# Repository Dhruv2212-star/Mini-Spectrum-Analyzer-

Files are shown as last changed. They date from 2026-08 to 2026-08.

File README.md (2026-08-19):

**Ai ussage**- used to find correct parts for the build and help choose the correct MCU for this project & debugging the firmware and  STM32 **ONLY**.  

**Project Description**- The Mini Spectrum Analyzer is a compact electronic device designed to detect and display radio frequency (RF) signals over a selected frequency range. 

It uses an ADF4351 frequency synthesizer to generate a programmable local oscillator and an ADL5801 mixer to convert the received RF signal into an intermediate frequency.  

The AD8313 logarithmic detector measures the signal strength, while the STM32G031K8T6 microcontroller processes the data and displays the spectrum on an SPI TFT display.  

Power input- The device is powered through a USB-C connector and includes onboard power regulation, protection circuitry, user control buttons, status indicators for easy debugging.  

*Designed in Kicad 10.0.3 as 4 layered PCB with independent power planes such as GND & +3v3*

**Note to reviewer**- the Format of the Readme is kept in tabular manner to keep things organized and easy to read. instead of long para i have used tables which i created in excel and pasted it into git file;. if you do have any further question regarding to my project, feel free to reach out to me on slack where i can explain it to you if you want.  
**[slack id- U0AFT499S6S,  Magic tree/Dhruv Patel]**
------------------------------------------------------------------------------------------------------------------------------------------
# Firmware Flashing Guide  
Don't flash the ZIP directly, The ZIP contains the ADF4351 driver source, not a ready-to-flash .bin  
You first need an STM32 project that compiles it, Create the STM32 project In STM32CubeIDE, create a project for: STM32G031K8T6  
Then configure the pins to match our PCB 
The ADF4351 uses a 3-wire serial interface and accepts a programmable 35 MHz–4.4 GHz output range.  
Now *Configure SPI1  
In CubeMX the following:  
SPI1 → Master  
8-bit  
MSB first  
CPOL = Low  
CPHA = 1st Edge  
Software NSS  
Configure PA4, PA5 and PA7 for the SPI interface, with PA4 ultimately serving as the ADF4351 LE control  
Add the driver. From the ZIP, copy: adf4351.h, adf4351.c  

into your CubeIDE project:  
Core/Inc/adf4351.h  
Core/Src/adf4351.c  
Then copy the initialization from: Maine.c to main.c  
now, Set your actual reference  
Our PCB uses:  
Y1 = 10 MHz TCXO  
hz = 10000000UL  
The ADF4351's reference/PFD configuration is important because it directly affects the generated frequency.  
->Build the project  
In CubeIDE:  
Project → Build Project  

 If it has:  
0 errors  
0 warnings related to the driver, ONLY then proceed 

*Connect your ST-LIN  
Use your J4 SWD header:  
J4-1 > SWDIO  
J4-2 > SWCLK   
J4-3 > NRST  
J4-4 > +3V3 / VTREF  
J4-5 > GND  
First test: don't test the spectrum analyzer yet  

Connect the ST-LINK to your PC and open STM32CubeProgrammer. ST officially supports programming STM32 devices through ST-LINK/SWD, and CubeProgrammer can program and verify the MCU flash  
Click:  
ST-LINK > SWD > Connect  
If it detects your STM32G031, stop there and tell me that it connected successfully.  
**Then we'll flash it**  
Compile > generate .elf > flash > reset > verify ADF4351 lock > check RF output  

so the driver is configured for:  

| STM32 U5 | ADF4351 U3 |
| --- | --- |
| PA4 — pin 11 | LE — pin 3 |
| PA5 — pin 12 | CLK — pin 1  |
| PA7 — pin 14 | DATA — pin 2 |
| PB0 — pin 15 | CE — pin 4 |
| PA1 — pin 8  | LD — pin 25  |

------------------------------------------------------------------------------------------------------------------------------------------
# PCB component's Role in the circuit 
 # Block 1 — USB-C Power Input & Protection
   

 | Ref | Component        | Role in the Circuit    |                                                                                     
| --- | ---------------- | ----------------------------------------------------------------------------------------------------------------------------------------- |
| J1  | USB-C Receptacle | Receives 5 V power from a USB-C source and serves as the main power input to the spectrum analyzer.                                          |
| F1  | Polyfuse         | Protects the board from excessive current by disconnecting the supply during a fault and automatically resetting after the fault is removed. |
| D1  | TVS/ESD Diode    | Protects the USB power line against electrostatic discharge and voltage spikes that could damage sensitive components.                       |
| R1  | 5.1 kΩ           | USB-C CC1 pull-down resistor that identifies the board as a power sink.                                                                      |
| R2  | 5.1 kΩ           | USB-C CC2 pull-down resistor that enables correct cable orientation detection.                                                               |
| C1  | 10 µF            | Reduces low-frequency voltage ripple and provides energy storage during sudden load changes.                                                 |
| C2  | 100 nF           | Filters high-frequency noise on the incoming USB power line.                                                                                 |

# Block 2 — 5 V to 3.3 V Power Regulation
  

| Ref | Component | Role in the Circuit |
| --- | --- | --- |
| U1  | 3.3 V Regulator | Converts the incoming 5 V supply into a stable 3.3 V rail for the digital and RF circuitry. |
| L1  | Ferrite Bead | Suppresses high-frequency switching noise between the regulator and the clean 3.3 V rail. |
| C3  | 10 µF | Stabilizes the regulator input and output while improving transient response. |
| C4  | 100 nF | High-frequency bypass capacitor for the regulator output. |
| C5  | 100 nF | Additional local decoupling capacitor to maintain a clean supply. |

# Block 3 — RF Input & Signal Conditioning
  

| Ref | Component | Role in the Circuit |
| --- | --- | --- |
| R6  | 10 Ω | Provides input damping and limits RF transients entering the signal path. |
| R7  | 10 Ω | Works with R6 to improve signal integrity and reduce ringing. |
| C6  | 100 pF | AC-couples the RF signal while blocking DC from reaching the mixer stage. |
| D2  | PESD5V0X1UL | Protects the RF input against electrostatic discharge events. |

# Block 4 — RF Detector & Block 5 — Frequency Generation, Mixer & IF Stage  


| Ref | Component | Role in the Circuit |
| --- | --- | --- |
| U2 | AD8313 | Converts the RF signal level into a proportional DC voltage that the MCU can measure. |
| C7–C10 | Decoupling Capacitors | Filter supply noise and maintain stable operation of the RF detector. |

| REf | Component | Role in the Circuit |
| --- | --- | --- |
| U3 | ADF4351 | Generates a programmable local oscillator signal used to sweep the analyzer across different frequencies. |
| U4 | ADL5801 | Mixes the incoming RF signal with the local oscillator to produce an intermediate-frequency signal. |
| Y1 | 10 MHz TCXO | Provides a highly stable reference clock for accurate frequency generation. |
| T1 | ADT4-1T+ Transformer | Converts the differential IF signal into the required form while providing impedance matching. |
| R11–R15 | Bias / PLL Resistors | Set PLL operating conditions, bias RF outputs, and configure the frequency synthesizer. |
| C11–C22 | Coupling / Decoupling Capacitors | Provide AC coupling, supply filtering, RF bypassing, and PLL loop-filter functions required for stable RF operation. |

# Block 6 — MCU, Display & Programming & Block 7 — User Interface  


| Ref | Component | Role in the Circuit |
| --- | --- | --- |
| U5  | STM32G031K8T6 | Controls the analyzer, programs the synthesizer, samples detector data, processes measurements, and updates the display. |
| J3  | ST7789 Display Module | Displays the measured spectrum, menus, and analyzer information to the user. |
| J4  | SWD Header | Allows firmware programming and debugging of the microcontroller. |
| R16 | 10 kΩ | Pull-up resistor for the MCU reset pin, ensuring reliable startup. |
| C24 | 100 nF | High-frequency bypass capacitor for the MCU supply. |
| C25 | 4.7 µF | Bulk decoupling capacitor that stabilizes the MCU power rail during rapid current changes. |

| Ref | Component | Role in the Circuit |
| --- | --- | --- |
| SW1 | Push Button | Increases frequency or navigates upward through menus. |
| SW2 | Push Button | Decreases frequency or navigates downward through menus. |
| SW3 | Push Button | Selects menu options and confirms user actions. |
| R17 | 10 kΩ | Pull-up resistor for SW1 input. |
| R18 | 10 kΩ | Pull-up resistor for SW2 input. |
| R19 | 10 kΩ | Pull-up resistor for SW3 input. |
screenshot of PCB

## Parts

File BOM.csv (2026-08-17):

Reference | Value | Quantity | Symbol | Footprint
J1 | USB-C Receptacle | 1 | Connector_USB:USB_C_Receptacle_HRO_TYPE-C-31-M-12 | Connector_USB:USB_C_Receptacle_HRO_TYPE-C-31-M-12
F1 | Polyfuse | 1 | Device:Polyfuse | Fuse:Fuse_1206_3216Metric
D1 | ESD/TVS | 1 | Device:D_TVS | Diode_SMD:D_SOD-323
C1 | 10uF | 1 | Device:C | Capacitor_SMD:C_0603_1608Metric
C2 | 100nF | 1 | Device:C | Capacitor_SMD:C_0603_1608Metric
U1 | 3.3V Regulator | 1 | Regulator_Linear | Package_TO_SOT_SMD:SOT-23-5
L1 | Ferrite Bead | 1 | Device:L | Inductor_SMD:L_0603_1608Metric
C3 | 10uF | 1 | Device:C | Capacitor_SMD:C_0603_1608Metric
C4 | 100nF | 1 | Device:C | Capacitor_SMD:C_0603_1608Metric
C5 | 100nF | 1 | Device:C | Capacitor_SMD:C_0603_1608Metric
R6 | 10Ω | 1 | Device:R | Resistor_SMD:R_0603_1608Metric
R7 | 10Ω | 1 | Device:R | Resistor_SMD:R_0603_1608Metric
C6 | 100pF | 1 | Device:C | Capacitor_SMD:C_0603_1608Metric
D2 | PESD5V0X1UL | 1 | Device:D | Diode_SMD:D_SOD-882
U2 | AD8313 | 1 | RF:AD8313 | Package_TO_SOT_SMD:SOT-363_SC-70-6
U3 | ADF4351 | 1 | Timer_PLL:ADF4351 | Package_DFN_QFN:LFCSP-32_5x5mm_P0.5mm
U4 | ADL5801 | 1 | RF_Mixer:ADL5801 | Package_DFN_QFN:LFCSP-24_4x4mm_P0.5mm
Y1 | 10MHz TCXO | 1 | Oscillator:TCXO | Oscillator:Oscillator_SMD_2.0x1.6mm
T1 | ADT4-1T+ | 1 | Transformer:ADT4-1T | RF_Mini-Circuits:Mini-Circuits_CD542_H2.84mm
R11 | 50Ω | 1 | Device:R | Resistor_SMD:R_0603_1608Metric
R12 | 50Ω | 1 | Device:R | Resistor_SMD:R_0603_1608Metric
R13 | 5.1kΩ | 1 | Device:R | Resistor_SMD:R_0603_1608Metric
R14 | PLL Filter | 1 | Device:R | Resistor_SMD:R_0603_1608Metric
R15 | 50Ω | 1 | Device:R | Resistor_SMD:R_0603_1608Metric
C11 | 1nF | 1 | Device:C | Capacitor_SMD:C_0603_1608Metric
C12 | 1nF | 1 | Device:C | Capacitor_SMD:C_0603_1608Metric
C13 | 1nF | 1 | Device:C | Capacitor_SMD:C_0603_1608Metric
C14 | 100pF | 1 | Device:C | Capacitor_SMD:C_0603_1608Metric
C15 | 100pF | 1 | Device:C | Capacitor_SMD:C_0603_1608Metric
C16 | 100nF | 1 | Device:C | Capacitor_SMD:C_0603_1608Metric
C17 | 100nF | 1 | Device:C | Capacitor_SMD:C_0603_1608Metric
C18 | 100nF | 1 | Device:C | Capacitor_SMD:C_0603_1608Metric
C19 | 100nF | 1 | Device:C | Capacitor_SMD:C_0603_1608Metric
C20 | 100nF | 1 | Device:C | Capacitor_SMD:C_0603_1608Metric
C21 | 100nF | 1 | Device:C | Capacitor_SMD:C_0603_1608Metric
C22 | 100nF | 1 | Device:C | Capacitor_SMD:C_0603_1608Metric
U5 | STM32G031K8T6 | 1 | MCU_ST_STM32G0:STM32G031K8Tx | Package_QFP:LQFP-32_7x7mm_P0.8mm
U6 | ST7789 Module | 1 | Connector_Generic:Conn_01x12 | Connector_PinHeader_2.54mm:PinHeader_1x12_P2.54mm_Vertical
J4 | SWD Header | 1 | Connector_Generic:Conn_01x05 | Connector_PinHeader_2.54mm:PinHeader_1x05_P2.54mm_Vertical
R16 | 10kΩ | 1 | Device:R | Resistor_SMD:R_0603_1608Metric
C24 | 100nF | 1 | Device:C | Capacitor_SMD:C_0603_1608Metric
C25 | 4.7uF | 1 | Device:C | Capacitor_SMD:C_0603_1608Metric
SW1 | Tactile Switch | 1 | Switch:SW_Push | Button_Switch_SMD:SW_SPST_SKQG_WithoutStem
SW2 | Tactile Switch | 1 | Switch:SW_Push | Button_Switch_SMD:SW_SPST_SKQG_WithoutStem
SW3 | Tactile Switch | 1 | Switch:SW_Push | Button_Switch_SMD:SW_SPST_SKQG_WithoutStem
R17 | 10kΩ | 1 | Device:R | Resistor_SMD:R_0603_1608Metric
R18 | 10kΩ | 1 | Device:R | Resistor_SMD:R_0603_1608Metric
R19 | 10kΩ | 1 | Device:R | Resistor_SMD:R_0603_1608Metric
D3 | Green LED | 1 | Device:LED | LED_SMD:LED_0603_1608Metric
R20 | 1kΩ | 1 | Device:R | Resistor_SMD:R_0603_1608Metric
TP1 | +5V | 1 | Connector:TestPoint | TestPoint:TestPoint_Pad_D1.5mm
TP2 | +3V3 | 1 | Connector:TestPoint | TestPoint:TestPoint_Pad_D1.5mm
TP3 | GND | 1 | Connector:TestPoint | TestPoint:TestPoint_Pad_D1.5mm
TP4 | RF | 1 | Connector:TestPoint | TestPoint:TestPoint_Pad_D1.5mm

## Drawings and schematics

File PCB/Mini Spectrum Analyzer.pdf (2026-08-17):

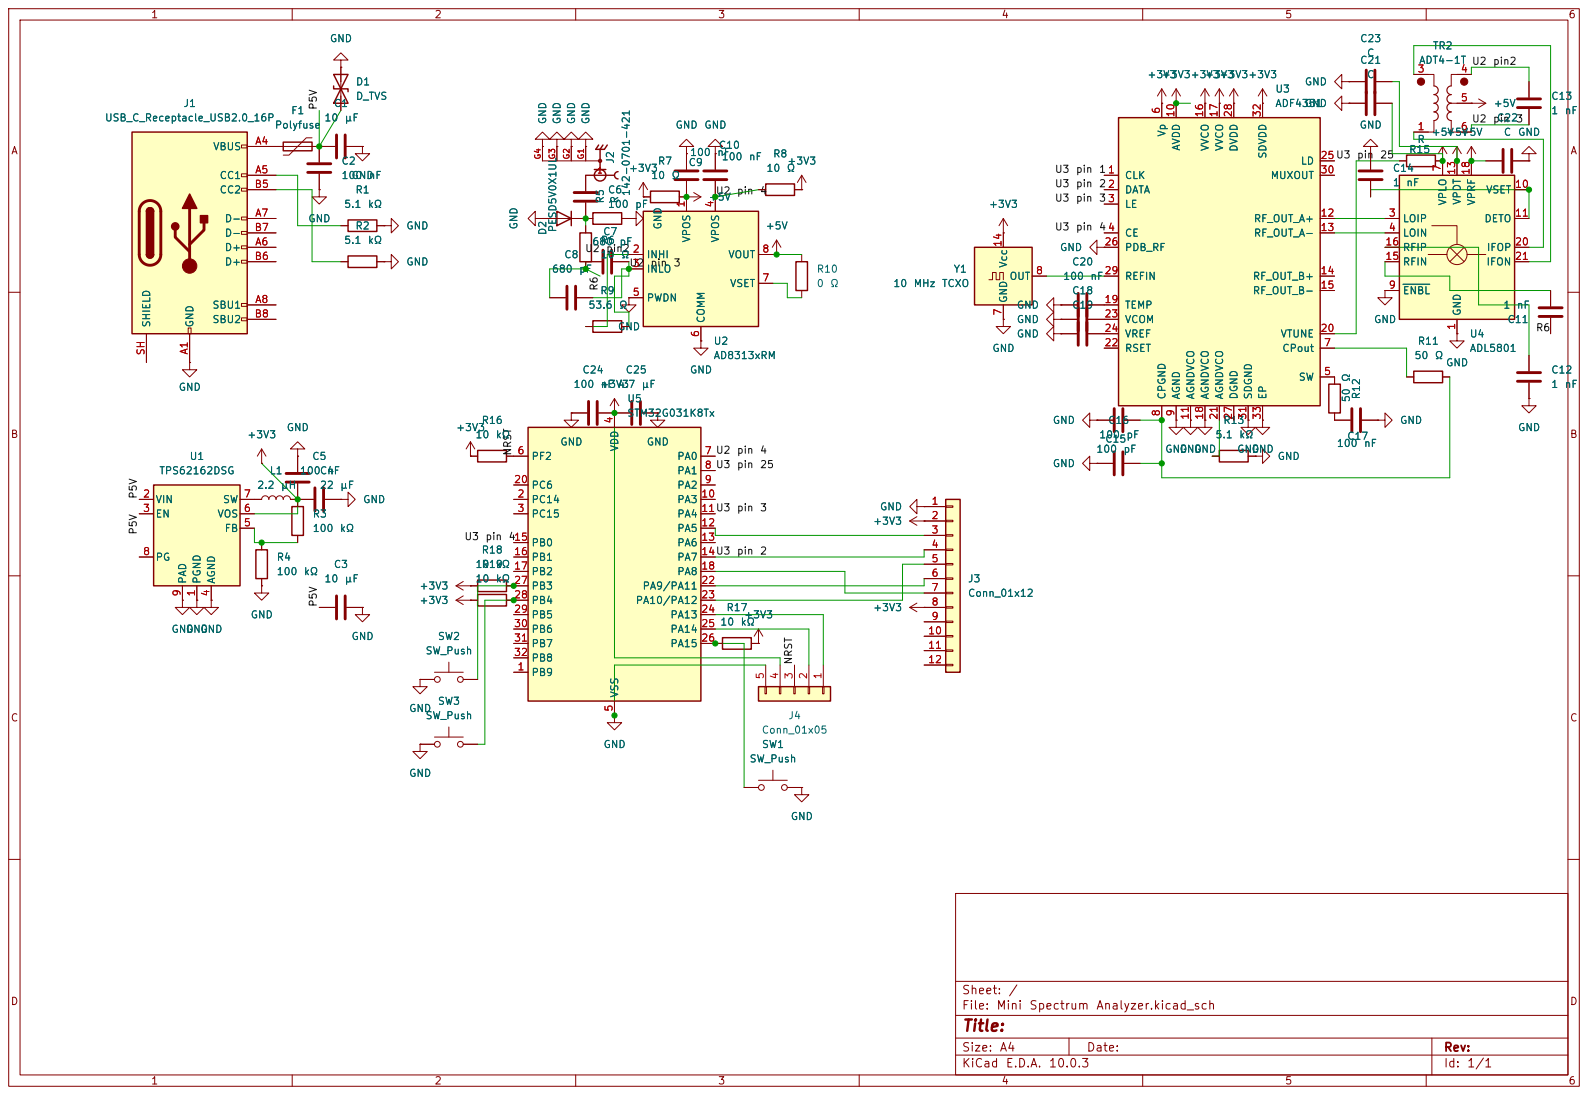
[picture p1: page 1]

9 AVDD 10 AGNDVCO 11 RF_OUT_A+ 12 RF_OUT_A- 13 RF_OUT_B+ 14 RF_OUT_B- 15 VVCO 16 VVCO 17 AGNDVCO 18

Sheet: /
File: Mini Spectrum Analyzer.kicad_sch
Title:

Size: A4 | Rev:
KiCad E.D.A. 10.0.3 | Id: 1/1

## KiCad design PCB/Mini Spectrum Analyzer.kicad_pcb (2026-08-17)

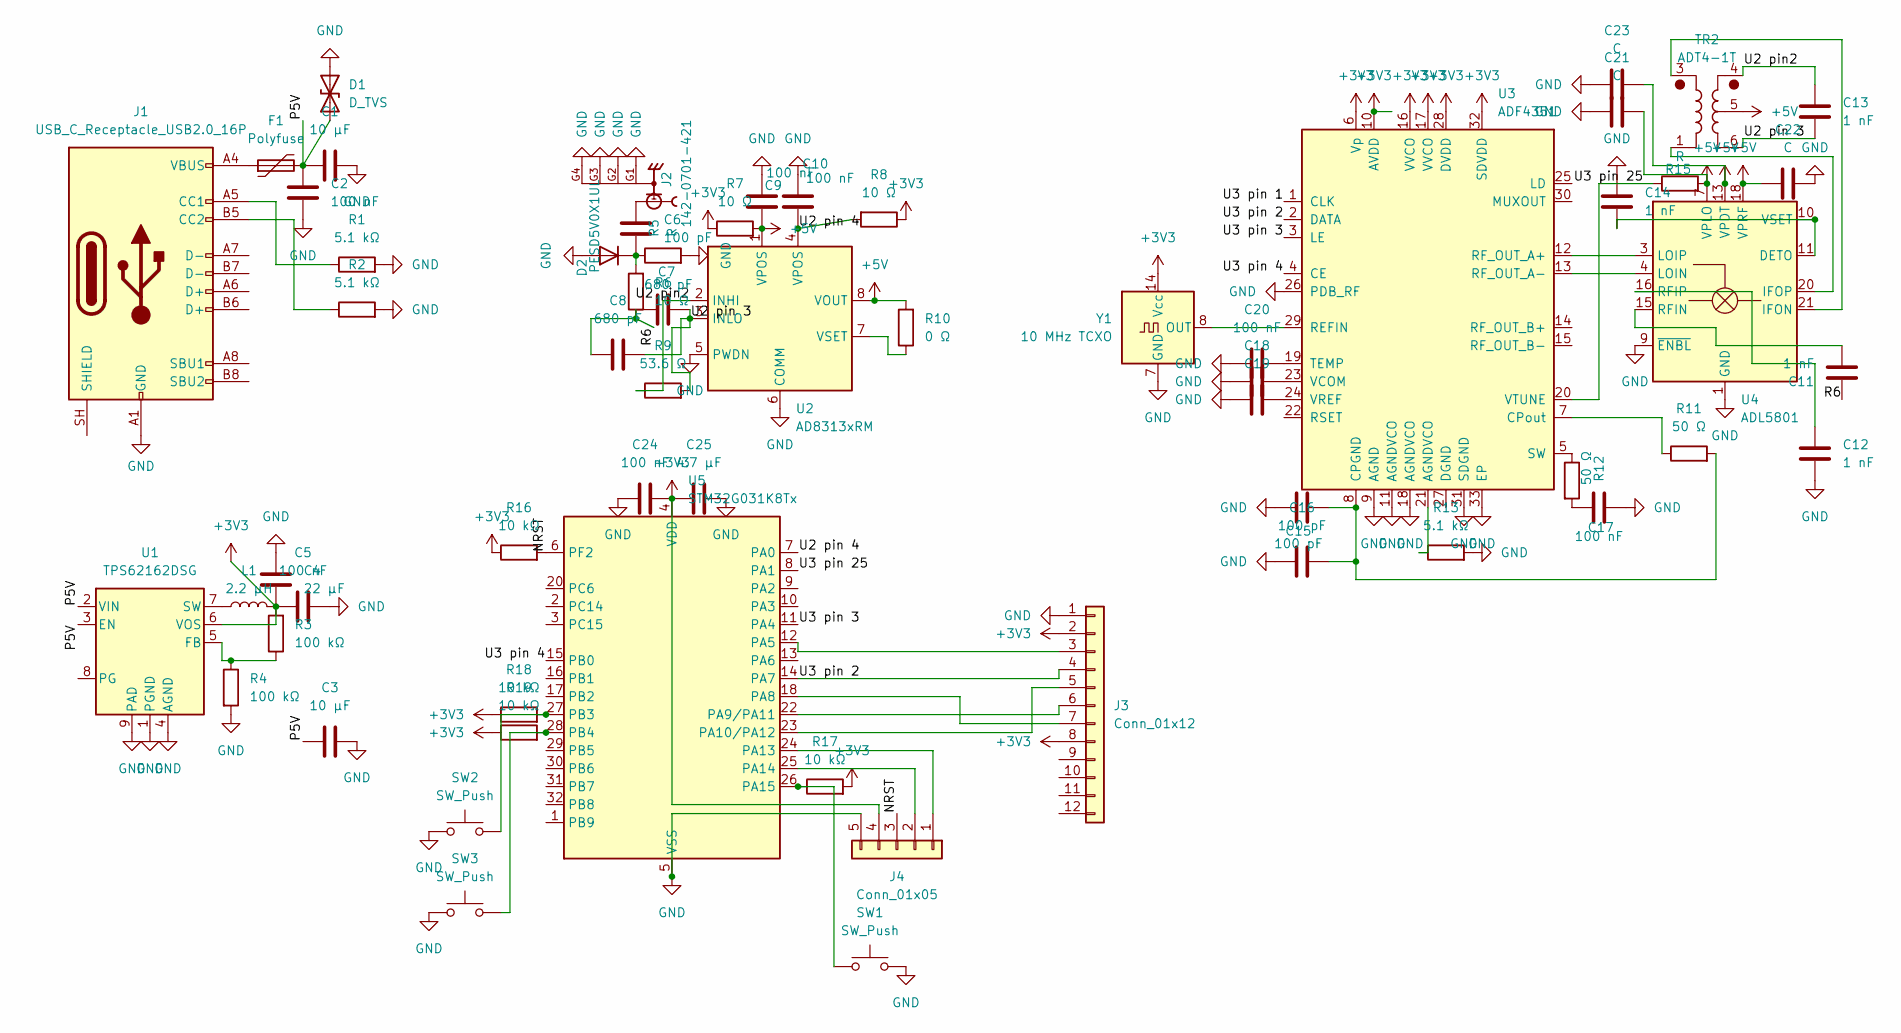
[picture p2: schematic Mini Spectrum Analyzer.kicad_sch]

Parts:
C1: 10 µF; C_1206_3216Metric
C2, C5, C9, C10, C17, C20, C24: 100 nF; C_0603_1608Metric
C3: 10 µF; C_0805_2012Metric
C4: 22 µF; C_0805_2012Metric
C6, C15, C16: 100 pF; C_0603_1608Metric
C7, C8: 680 pF; C_0603_1608Metric
C11, C12, C13, C14: 1 nF; C_0603_1608Metric
C18, C19: C_0603_1608Metric
C21, C22, C23: C; C_0603_1608Metric
C25: 4.7 µF; C_0603_1608Metric
D1: D_TVS; D_SMB
D2: PESD5V0X1UL; D_SOD-523
F1: Polyfuse; Fuse_1206_3216Metric
J1: USB_C_Receptacle_USB2.0_16P; USB_C_Receptacle_GCT_USB4105-xx-A_16P_TopMnt_Horizontal
J2: 142-0701-421; CINCH_142-0701-421; PARTREV 1a
J3: Conn_01x12; PinHeader_1x12_P2.54mm_Vertical
J4: Conn_01x05; PinHeader_1x05_P2.54mm_Vertical
L1: 2.2 µH; L_1210_3225Metric
R1, R2, R13: 5.1 kΩ; R_0603_1608Metric
R3, R4: 100 kΩ; R_0603_1608Metric
R5, R15: R; R_0603_1608Metric
R6, R7, R8: 10 Ω; R_0603_1608Metric
R9: 53.6 Ω; R_0603_1608Metric
R10: 0 Ω; R_0603_1608Metric
R11, R12: 50 Ω; R_0603_1608Metric
R16, R17, R18, R19: 10 kΩ; R_0603_1608Metric
SW1, SW2, SW3: SW_Push; SW_SPST_SKQG_WithoutStem
TR2: ADT4-1T; Mini-Circuits_CD542_H2.84mm
U1: TPS62162DSG; WSON-8-1EP_2x2mm_P0.5mm_EP0.9x1.6mm_ThermalVias
U2: AD8313xRM; MSOP-8_3x3mm_P0.65mm
U3: ADF4351; LFCSP-32-1EP_5x5mm_P0.5mm_EP3.25x3.25mm
U4: ADL5801; LFCSP-VQ-24-1EP_4x4mm_P0.5mm_EP2.642x2.642mm
U5: STM32G031K8Tx; LQFP-32_7x7mm_P0.8mm
Y1: 10 MHz TCXO; Oscillator_DIP-14

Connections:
+3V3: C4.2, C5.1, C24.2, C25.1, J3.2, J3.8, J4.4, L1.2, R3.2, R7.1, R8.1, R16.1, R17.2, R18.1, R19.1, U1.6 (VOS), U3.6 (Vp), U3.10 (AVDD), U3.16 (VVCO), U3.17 (VVCO), U3.28 (DVDD), U3.32 (SDVDD), U5.4 (VDD), Y1.14 (Vcc)
+5V: C9.2, C21.2, C22.1, C23.2, R7.2, R10.2, R15.2, TR2.5, U2.1 (VPOS), U2.8 (VOUT), U4.7 (VPLO), U4.13 (VPDT), U4.18 (VPRF), U4.24 (VPLO)
/NRST: J4.3, R16.2, U5.6 (PF2)
/P5V: C1.1, C2.1, C3.1, D1.1 (A1), F1.2, U1.2 (VIN), U1.3 (EN)
/R6: C7.1, C8.1, C11.1, R6.1
/U2 pin2: C13.1, R9.1, TR2.4, U2.2 (INHI)
/U2 pin 3: C7.2, C8.2, C13.2, R9.2, TR2.6, U2.3 (INLO)
/U2 pin 4: C10.2, R8.2, U2.4 (VPOS), U5.7 (PA0)
/U3 pin 1: U3.1 (CLK)
/U3 pin 2: J3.4, U3.2 (DATA), U5.14 (PA7)
/U3 pin 3: U3.3 (LE), U5.11 (PA4)
/U3 pin 4: U3.4 (CE), U5.15 (PB0)
/U3 pin 25: U5.8 (PA1)
GND: C1.2, C2.2, C3.2, C4.1, C5.2, C9.1, C10.1, C12.2, C14.1, C15.1, C16.1, C17.2, C18.1, C19.1, C20.1, C21.1, C22.2, C23.1, C24.1, C25.2, D1.2 (A2), D2.2 (A), J1.A1 (GND), J1.A12 (GND), J1.B1 (GND), J1.B12 (GND), J2.G1, J2.G2, J2.G3, J2.G4, J3.1, J4.5, R1.2, R2.2, R4.2, R5.2, R13.2, SW1.2, SW2.1, SW3.1, U1.1 (PGND), U1.4 (AGND), U1.9 (PAD), U2.5 (PWDN), U2.6 (COMM), U3.9 (AGND), U3.11 (AGNDVCO), U3.18 (AGNDVCO), U3.26 (PDB_RF), U3.31 (SDGND), U3.33 (EP), U4.1 (GND), U4.2 (GND), U4.5 (GND), U4.6 (GND), U4.8 (GND), U4.9 (~ENBL), U4.12 (GND), U4.14 (GND), U4.17 (GND), U4.19 (GND), U4.23 (GND), U4.25 (GND), U5.5 (VSS), Y1.7 (GND)
unnamed: C6.2, J2.1
unnamed: C17.1, R12.2
unnamed: C6.1, D2.1 (K), R5.1, R6.2
unnamed: F1.1, J1.A4 (VBUS), J1.A9 (VBUS), J1.B4 (VBUS), J1.B9 (VBUS)
unnamed: J1.A5 (CC1), R1.1
unnamed: J1.B5 (CC2), R2.1
unnamed: J3.3, U5.12 (PA5)
unnamed: J3.5, U5.23 (PA10/PA12)
unnamed: J3.6, U5.22 (PA9/PA11)
unnamed: J3.7, U5.18 (PA8)
unnamed: J4.1, U5.24 (PA13)
unnamed: J4.2, U5.25 (PA14)
unnamed: R13.1, U3.21 (AGNDVCO)
unnamed: R3.1, R4.1, U1.5 (FB)
unnamed: L1.1, U1.7 (SW)
unnamed: R10.1, U2.7 (VSET)
unnamed: C15.2, C16.2, R11.2, U3.8 (CPGND)
unnamed: R11.1, U3.7 (CPout)
unnamed: U3.29 (REFIN), Y1.8 (OUT)
unnamed: U3.12 (RF_OUT_A+), U4.3 (LOIP)
unnamed: U3.13 (RF_OUT_A-), U4.4 (LOIN)
unnamed: R12.1, U3.5 (SW)
unnamed: C20.2, U3.19 (TEMP)
unnamed: C18.2, U3.23 (VCOM)
unnamed: C19.2, U3.24 (VREF)
unnamed: R15.1, U3.20 (VTUNE)
unnamed: C14.2, U4.10 (VSET), U4.11 (DETO)
unnamed: TR2.3, U4.21 (IFON)
unnamed: TR2.1, U4.20 (IFOP)
unnamed: C11.2, U4.15 (RFIN)
unnamed: C12.1, U4.16 (RFIP)
unnamed: R17.1, SW1.1, U5.26 (PA15)
unnamed: R18.2, SW2.2, U5.27 (PB3)
unnamed: R19.2, SW3.2, U5.28 (PB4)

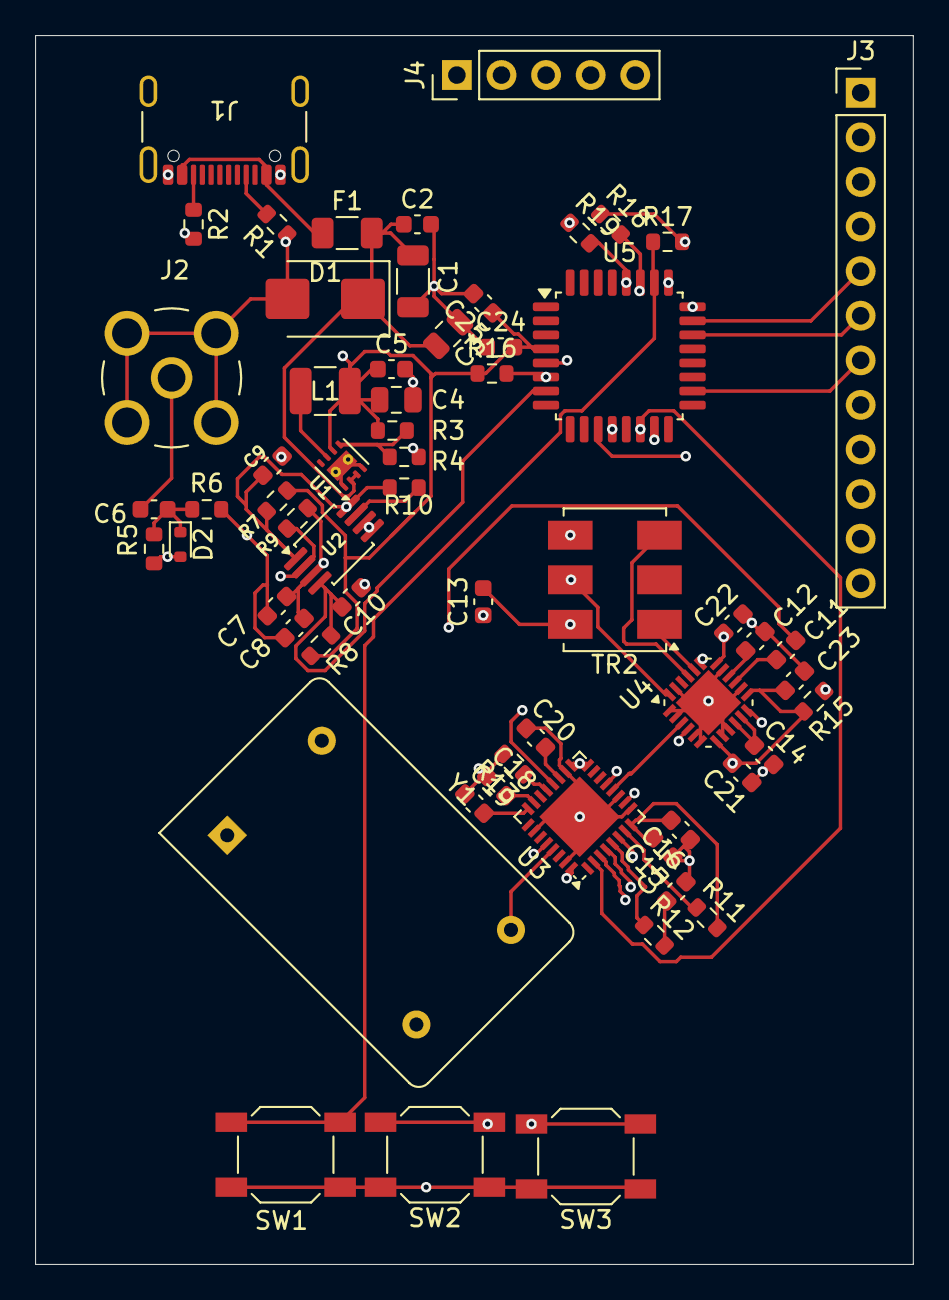
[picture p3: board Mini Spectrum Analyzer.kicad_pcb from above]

Board: 4 copper layers, 50.0 x 70.0 mm, 61 parts (0 on the bottom side), 46 nets.

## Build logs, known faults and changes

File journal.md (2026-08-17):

# Block 1 — USB-C Power Input & Protection (30 mins) 
lapse 1 (schematic)- https://lapse.hackclub.com/timelapse/WdHtK5_evs1y  
lapse 2- (pcb tracing)- https://lapse.hackclub.com/timelapse/TA8tFFjn7U0u  

# Block 2 — 5V to 3.3V Power Regulation (37 mins) 
lapse- https://lapse.hackclub.com/timelapse/30pn2lQfJgP9  

# block 3- 3.3V Power Filtering & Distribution (43 mins) & block 4- RF Input / Signal Conditioning combined (43 mins + 1 hour) 
Lapse block 3- https://lapse.hackclub.com/timelapse/bzj2jMwLS-7o  
Lapse block 4- https://lapse.hackclub.com/timelapse/6fH-dU1CGsFC  

# block 5- Frequency Generation, Mixing & IF Detection
Lapse- https://lapse.hackclub.com/timelapse/uksiBaG2r4nT  
ps- block almost made me cry because of the complexity so pls ignore the messy diagrams and still images in some parts of the lapse,  
i had to go through 500 pages of data sheets which i was not able to switch to :)   

# block 6 MCU, Display & Programming
Lapse 1- https://lapse.hackclub.com/timelapse/BTViIKsYV-Nq  
Lapse 2- https://lapse.hackclub.com/timelapse/OMG9x9yIFDE2  
Lapse 3 (PCB tracings)- https://lapse.hackclub.com/timelapse/cahCFqq3hA76  
# Block 7 User Interface (Buttons)
Lapse (schematic)- https://lapse.hackclub.com/timelapse/OVqnNE-gKsbp (13 mins)  
Lapse (PCB tracing)- https://lapse.hackclub.com/timelapse/pfFoFq8A9Dp2  



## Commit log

2026-08-17 Development files
    [BOM.csv, Mini Spectrum Analyzer.kicad_pcb, Mini Spectrum Analyzer.kicad_sch]
2026-08-17 Add PCB screenshot
    Added an image of the PCB to the README for better visualization.
2026-08-19 Firmware details and project details updated
    Updated the README to enhance project details, including usage, description, firmware flashing guide, and PCB components. Added formatting improvements for better readability.
